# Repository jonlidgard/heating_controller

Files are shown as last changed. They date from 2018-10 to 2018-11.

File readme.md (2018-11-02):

# Raspberry Pi Based Heating Controller

The circuit for this is stored under the kicad directory

# Adafruit Python MCP3008

Python code to use the MCP3008 analog to digital converter with a Raspberry Pi or BeagleBone black.

## Installation

To install the library from source (recommended) run the following commands on a Raspberry Pi or other Debian-based OS system:

    sudo apt-get install git build-essential python-dev
    cd ~
    git clone https://github.com/adafruit/Adafruit_Python_MCP3008.git
    cd Adafruit_Python_MCP3008
    sudo python setup.py install

Alternatively you can install from pip with:

    sudo pip install adafruit-mcp3008

Note that the pip install method **won't** install the example code.

#WiringPi

See jonsblog.lidgard.uk/cross-compile
and info held in cpp/build-libDigiPot

# Heating Controller Code

## This code should be run as a daemon

The heating controller connects to a worcester-bosch combi boiler via the TR2 interface (3 4 F) & acts to control demand for heating.
It has it's own TR2 interface for connecting to the existing thermostat but also has 3 'Call For Heat' connections to allow Nest & other devices to control the boiler in a zoned setup.

Control Flow:
* Set the Boiler output to be off using the X9C digital programmable pots.
* Read the TR2 resistances between 3&4 & F&4 to get thermostat mode and sensed temperature.
* Drive the zone valve & when the zone valve is open:
* Set the Boiler output to mimic those resistances using the X9C digital programmable pots.
* If any CFH contacts made, 

Set the X9C to

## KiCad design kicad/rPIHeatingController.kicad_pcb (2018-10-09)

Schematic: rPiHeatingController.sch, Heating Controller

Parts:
C1, C2, C3, C4, C5, C6, C7, C8, C9, C10, C11, C12, C13, C14: 100n; C_Rect_L4.0mm_W2.5mm_P2.50mm
J1, J2, J15: Screw_Terminal_01x03; TerminalBlock_Altech_AK300-3_P5.00mm
J3, J4, J5, J11, J12, J13, J17, J19: Screw_Terminal_01x02; TerminalBlock_Altech_AK300-2_P5.00mm
J6, J7, J8, J9, J14, J16, J18: Conn_01x06; Pin_Header_Straight_1x06_Pitch2.54mm
J10: Raspberry_Pi_2_3; Socket_Strip_Angled_2x20_Pitch2.54mm
J20: Conn_01x10; Socket_Strip_Straight_1x10_Pitch2.54mm
J21: Conn_01x04_Female; Socket_Strip_Straight_1x04_Pitch2.54mm
J22: Conn_01x03_Female; Socket_Strip_Straight_1x03_Pitch2.54mm
R1, R2, R3, R4, R5, R6: 330R; R_Axial_DIN0207_L6.3mm_D2.5mm_P7.62mm_Horizontal
R7: 4k7; R_Axial_DIN0207_L6.3mm_D2.5mm_P7.62mm_Horizontal
R8: 1k; R_Axial_DIN0207_L6.3mm_D2.5mm_P7.62mm_Horizontal
R9, R11: 3k3; R_Axial_DIN0207_L6.3mm_D2.5mm_P7.62mm_Horizontal
R10: 5k6; R_Axial_DIN0207_L6.3mm_D2.5mm_P7.62mm_Horizontal
R12: 15k; R_Axial_DIN0207_L6.3mm_D2.5mm_P7.62mm_Horizontal
TP1, TP2, TP3: TestPoint; Pin_Header_Angled_1x01_Pitch2.54mm
U1, U2: X9C103P; DIP254P762X533-8
U3: MCP3008; DIP-16_W7.62mm

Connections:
+3V3: J8.3, J9.5, J15.1, J16.5, J20.2, J22.2, R7.1, R8.1, R11.1, R12.1, TP1.1, U3.15 (Vref), U3.16 (Vdd)
+5V: C9.1, C10.1, C11.1, C12.1, C13.1, C14.1, J6.3, J10.2, J10.4, J17.1, J18.1, J20.1, J21.4, J22.1, R1.1, R2.1, R3.1, R4.1, R5.1, R6.1, TP3.1, U1.8, U2.8
ADC1: C1.1, J1.1, R11.2, U3.1 (CH0)
ADC2: C2.1, J1.2, R12.2, U3.2 (CH1)
ADC3: J19.2, R8.2, U3.3 (CH2)
ADC_CLK: J10.12, U3.13 (CLK)
ADC_CS: J10.13, U3.10 (~CS~/SHDN)
ADC_DIN: J10.37, U3.11 (Din)
ADC_DOUT: J10.22, U3.12 (Dout)
CFH1: J9.1, J10.7
CFH2: J9.2, J10.29
CFH3: J9.3, J10.31
CS1_3V: J8.1, J10.35
CS1_5V: J6.1, U1.7
CS2_3V: J8.2, J10.38
CS2_5V: J6.2, U2.7
DS18B20: J10.26, J15.2, R7.2
GND: C1.2, C2.2, C3.2, C4.2, C5.2, C6.2, C7.2, C8.2, C9.2, C10.2, C11.2, C12.2, C13.2, C14.2, J1.3, J3.1, J4.1, J5.1, J6.4, J7.6, J8.4, J9.6, J10.6, J10.9, J10.14, J10.20, J10.25, J10.30, J10.34, J10.39, J11.1, J12.1, J13.1, J14.6, J15.3, J16.6, J17.2, J18.6, J19.1, J20.10, J21.1, J22.3, TP2.1, U1.4, U2.4, U3.9 (DGND), U3.14 (AGND)
INC_3V: J8.5, J10.36
INC_5V: J6.5, U1.1, U2.1
unnamed: C3.1, J3.2, J7.2, R1.2
unnamed: C4.1, J4.2, J7.3, R2.2
unnamed: C5.1, J5.2, J7.4, R3.2
unnamed: C6.1, J11.2, J14.2, R4.2
unnamed: C7.1, J12.2, J14.3, R5.2
unnamed: C8.1, J13.2, J14.4, R6.2
unnamed: J2.1, R9.2, U1.5
unnamed: J2.2, R10.1
unnamed: J2.3, R9.1, U1.6, U2.6
unnamed: J10.8, J21.3
unnamed: J10.10, J21.2
unnamed: J10.19, J20.5
unnamed: J10.21, J20.4
unnamed: J10.23, J20.6
unnamed: J10.24, J20.3
unnamed: J10.27, J20.7
unnamed: J10.28, J20.8
unnamed: J10.40, J20.9
unnamed: R10.2, U2.5
RL1: J10.3, J18.2
RL2: J10.5, J18.3
RL3: J10.32, J18.4
RL4: J10.33, J18.5
UD_3V: J8.6, J10.11
UD_5V: J6.6, U1.2, U2.2
ZV1: J10.15, J16.1
ZV2: J10.16, J16.2
ZV3: J10.18, J16.3

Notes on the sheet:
CFH1
CFH2
CFH3
ZV1
ZV2
ZV3
PWR
RELAYS
TEMP SENSORS
TR2
BOILER
OPTO BOARD
LEVEL SHIFTER
UFH Sensor

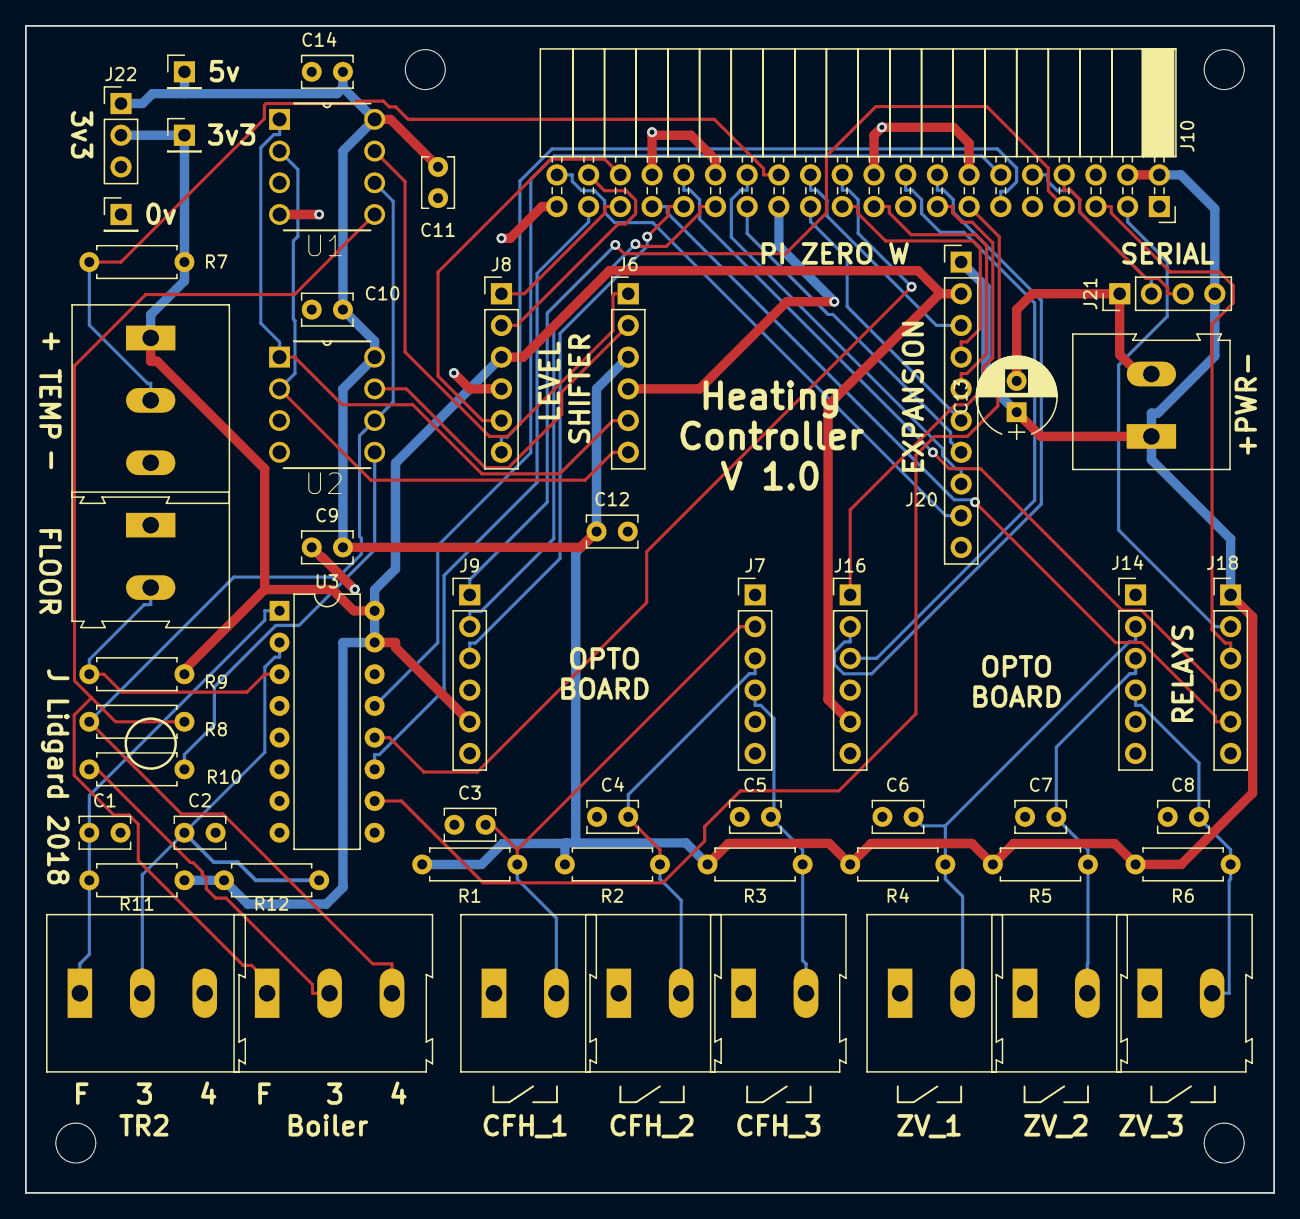
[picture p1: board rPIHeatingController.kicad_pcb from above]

Board: 2 copper layers, 100.0 x 93.5 mm, 54 parts (0 on the bottom side), 48 nets.

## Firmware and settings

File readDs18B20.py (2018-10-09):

# --------------------------------------------------------
# PURPOSE: - To monitor temperatures within a backup server's 
#            case and within the garden shed it is running in
#          - To turn on heating or cooling if temperature within
#            server case gets out of a predetermined range    
#          - To log temperatures/times in a tab-delimited file
#            on a NAS box. 

import os
import glob
import time
import datetime
import RPi.GPIO as iO
import os,subprocess
from subprocess import call
from w1thermsensor import W1ThermSensor

os.system('modprobe w1-gpio')
os.system('modprobe w1-therm')

# ======================================================================
# Define our subroutines:
# --------------------------------------------------
# Define a function to convert Celsius to Fahrenheit 

def celsiusToFahrenheit(theTempCelsius):
 myTempFarenheit = ((theTempCelsius*9)/5) + 32
 return myTempFarenheit
 
# --------------------------------------------------
# Define a function to get current temperature of the
# Raspberry Pi's CPU  (which, just for grins, we also
# want to monitor)

def getPiCPUtemperature():  
 res = os.popen('vcgencmd measure_temp').readline()  
 return(res.replace("temp=","").replace("'C\n",""))  
 
# --------------------------------------------------
# Define a function fo mount the NAS directory as 
# part of the Pi's file system

# NB: For reasons not yet discovered, using the NAS
#     box's name is not working, so we revert to 
#     it's numeric IP address.
#
#     //Giga2/D  works, no problem, but
#     //NAS/A    fails..... go figure....

def mountNasDirectory():
 myUNC="//10.0.0.8/A"
	
 myCmd = "sudo umount " + myLocalMountDir
 subprocess.Popen(myCmd, shell=True)
 
 myCmd = "sudo mount -t cifs " + myUNC + " " +  myLocalMountDir + " -o  uid=pi,gid=pi,user=admin,pass=xxx"
 subprocess.Popen(myCmd, shell=True)


# ======================================================================
# Perform startup processing: 

# -------------------------------------
# Specify the desired temprature range 
# and time between readings

caseTempDesiredC = int(25)
maxDeviation_BeforeCool = 1.5 
maxDeviation_BeforeHeat = 1.5 
secondsBetweenReadings = 60

# -------------------------------------
# Capture the date we started this script

myDateStamp_Startup =datetime.datetime.now().strftime("%Y-%m-%d")
myDateStamp_Today = myDateStamp_Startup

# -------------------------------------
# Specify NAS box directory in the Pi's
# file system's scheme of things
#
# NB: You might have to read up on this: somehow
#     this directory contains some sort of secret
#     sauce that allows the Pi's OS to populate it
#     with shortcuts to the actual NAS box's 
#     folders... possibly specified in the Samba
#     setup files.

myLocalMountDir="/mnt/NAS_A"
 
# -------------------------------------
# Refer to pins by Broadcom SOC channel
# instead of physical pin#

iO.setmode(iO.BCM)

# -------------------------------------
# Specify which pins are used to flip
# which relay switch on/off and then
# define them as "Output"

relayCool = 10
relayHeat = 11
iO.setwarnings(False)
iO.setup(relayCool, iO.OUT)
iO.setup(relayHeat, iO.OUT)

# -------------------------------------
# Turn off both relay switches - for 
# convenience in testing

iO.output(relayHeat, False)
iO.output(relayCool, False)

# -------------------------------------
# Specify the 3 possible heating/cooling states

tempStateNone = 0
tempStateCool = 1
tempStateHeat = 2 

# -------------------------------------
# Set a pointer to our W1Thermsensor object,
# which will give us easy access to the sensors

mySensor = W1ThermSensor()

# -------------------------------------
# Define sensors by ID (we had to experimentally
# discover these by writing a little script that
# opened the W1ThermSensor class, looped through
# the sensors it knew about and displayed "sensorID"
# for each sensor

sensorID_Case = "0000080222f8"
sensorID_Shed = "04165661cdff"

# -------------------------------------
# Mount the share on the NAS box that we
# will be writing the 2 logs to

mountNasDirectory()

# -------------------------------------
# Open the two tab-delimited log files on the
# NAS box: one for each 24-hour period the
# other cumulative since the last startup.
#
# NB: If either file already exists, we want to
#     open it for Append instead of new albeit 
#     with a blank line to call attention to the
#     fact that log entries were interrupted.
#
# NB: We have sometimes been having trouble with 
#     opening a new file failing w/ErrorCode=2 
#     even so the path is good - only to have
#     it work upon re-starting the script.  This
#     happens if/when somebody on another PC deleted
#     one or both log files while the script is running.

myLogFileDelim = "\t"

myFileHeader1 = myLogFileDelim.join(["\n" + "Temp Desired=" + str(caseTempDesiredC), "maxDeviation Before Cool=" + str(maxDeviation_BeforeCool), "maxDeviation Before Heat=" + str(maxDeviation_BeforeHeat)])
myFileHeader2 = myLogFileDelim.join(["\n" + "TimeStamp", "Case TempC ", "Heat/Cool State", "Shed TempC", "Shed TempF", "Pi CPU TempC"])
#myFileHeader2 = myLogFileDelim.join(["\n" + "TimeStamp", "Case TempC ", "Shed TempC", "Shed TempF", "Pi CPU TempC", "Heat/Cool State  (" + str(tempStateNone) +"=Nothing, " + str(tempStateCool) + "=Cool, " + str(tempStateHeat) + "=Heat)"])

myInterruptIndicator = myLogFileDelim.join(["\n" + "-"*45, "-"*45, "-"*45, "-"*45, "-"*45, "-"*45, "-"*45])

myLogFileSingleDay_Path = myLocalMountDir + "/Mongo_TemperatureLogs/MongoTempLog_SingleDay." + myDateStamp_Today + ".csv"
if os.path.exists(myLogFileSingleDay_Path):
	print("SingleDay: Append to Existing")
	logFileSingleDay = open(myLogFileSingleDay_Path, "a")
	logFileSingleDay.write(myInterruptIndicator)
	logFileSingleDay.write(myFileHeader1)
	logFileSingleDay.write(myFileHeader2)
		
else:	
	print("SingleDay: Create New")
	logFileSingleDay = open(myLogFileSingleDay_Path, "a")
	logFileSingleDay.write(myFileHeader1)
	logFileSingleDay.write(myFileHeader2)


myLogFileCumulative_Path = myLocalMountDir + "/Mongo_TemperatureLogs/MongoTempLog_Cumulative.csv"	
if os.path.exists(myLogFileCumulative_Path):
	print("Cumulative: Append to Existing")
	logFileCumulative = open(myLogFileCumulative_Path, "a")
	logFileCumulative.write(myInterruptIndicator)
	logFileCumulative.write(myFileHeader1)
	logFileCumulative.write(myFileHeader2)
else:	
	print("Cumulative: Create New")
	logFileCumulative = open(myLogFileCumulative_Path, "a")
	logFileCumulative.write(myFileHeader1)
	logFileCumulative.write(myFileHeader2)	
	
# ======================================================================
# Drop into the script's main loop, which keeps on executing until the
# script abends or is cancelled:
#
#    - Reading temp, 
#    - Checking to see if we need heating or cooling, and
#    - Writing temps to the log file

while True:
#   --------------------------------------------
#   See if we need to start a new 24-hour log
#
#   NB: re/"a" vs "w".... Greater Minds have decreed
#       there is no sense in using "w"... because
#       with "a" if the file does not exist, it 
#       gets created same as if we used "w".

	myDateStamp_Current  = datetime.datetime.now().strftime("%Y-%m-%d")
	
	if (myDateStamp_Current != myDateStamp_Today):
		myDateStamp_Today = myDateStamp_Current
		myLogFileSingleDay_Path = myLocalMountDir + "/Mongo_TemperatureLogs/MongoTempLog_SingleDay." + myDateStamp_Today + ".csv"
		logFileSingleDay = open(myLogFileSingleDay_Path, "a")
		logFileSingleDay.write(myFileHeader1)
		logFileSingleDay.write(myFileHeader2)	
		
#	--------------------------------------------
#   Loop through the available sensors (only 2 assumed,
#   for which we experimentally determined their IDs 
#   and hard-coded them into this script)
        
	for mySensor in W1ThermSensor.get_available_sensors():
		curSensorID = mySensor.id
		curTempC = round(float(mySensor.get_temperature()),1)
		myTimeStamp = datetime.datetime.now().strftime("%Y-%m-%d@%H:%M:%S")		

#       ---------------------------------------
#       Identify/assign temp as Case or Shed

		if curSensorID == sensorID_Case:
			myTempCaseC = curTempC
		elif curSensorID == sensorID_Shed:
			myTempShedC = curTempC
		else:
			print("Unexpected SensorID=" + curSensorID)
			
#       ---------------------------------------
#       When we have temps for both inside computer 
#       case and shed, turn heating/cooling on/off
#       accordingly and then write to the 2 logs
#
#       Yes, this will break if/when we do not have
#       both sensors present....

        if curSensorID == sensorID_Shed:
#    	    ---------------------------------------
#           Turn heating/cooling on/of as needed
          
			if myTempCaseC> (caseTempDesiredC + maxDeviation_BeforeCool):
				iO.output(relayHeat, False)
				iO.output(relayCool, True)
				curTempState = tempStateCool
			elif myTempCaseC < (caseTempDesiredC - maxDeviation_BeforeHeat):
				iO.output(relayCool, False)
				iO.output(relayHeat, True)
				curTempState = tempStateHeat
			else:
				iO.output(relayCool, False)
				iO.output(relayHeat, False)
				curTempState = tempStateNone
				
#    	    ---------------------------------------
#     	    Write to the logs, flushing the buffers 
#           of each so we can take a look at the files
#           from another PC even while this script is running
#
#           Why are we getting/logging the Pi's CPU temp?
#           In the immortal words of Alfred E. Neuman "Whyyyyyy not?"
#
#           NB that we check to see if each file is still there
#              and re-create as needed just in case somebody somewhere
#              managed to delete one or both log files at the "right"
#              moment
#
#           NB: The "mountNasDirectiory()" thing is an (unsucessful
#               for now...) attempt to get around mysterious "File 
#               Not Found" errors (Error 02)" if/when somebody on another
#               PC deletes one or both log files while the script is running

			myTempPiC = round(float(getPiCPUtemperature()),1)
			myTempCaseF = round(float(celsiusToFahrenheit(myTempCaseC)))
			myTempShedF = round(float(celsiusToFahrenheit(myTempShedC)))
			myLogFileLine = myLogFileDelim.join(["\n" + myTimeStamp, str(myTempCaseC), str(curTempState), str(myTempShedC), str(myTempShedF), str(myTempPiC)])
						
			if os.path.exists(myLogFileSingleDay_Path):
				logFileSingleDay = open(myLogFileSingleDay_Path, "a")
				logFileSingleDay.write(myLogFileLine)
				logFileSingleDay.close
			else:	
				myLogFileSingleDay_Path = myLocalMountDir + "/Mongo_TemperatureLogs/MongoTempLog_SingleDay." + myDateStamp_Startup + ".csv"				
				mountNasDirectory()
				logFileSingleDay = open(myLogFileSingleDay_Path, "a")					
				logFileSingleDay.write(myFileHeader1)
				logFileSingleDay.write(myFileHeader2)	
				logFileSingleDay.write(myLogFileLine)
				logFileSingleDay.close		
												
			if os.path.exists(myLogFileCumulative_Path):
				logFileCumulative = open(myLogFileCumulative_Path, "a")				
				logFileCumulative.write(myLogFileLine)
				logFileCumulative.close
			else:
				mountNasDirectory()	
				logFileCumulative = open(myLogFileCumulative_Path, "a")					
				logFileCumulative.write(myFileHeader1)
				logFileCumulative.write(myFileHeader2)			
				logFileCumulative.write(myLogFileLine)
				logFileCumulative.close

#     	  	-------------------------------------
#    	  	Just for testing/debugging, print some
#     	  	info on the console

			print("ServerCase=" + str(myTempCaseC) + "C / " + str(myTempCaseF) + "F  Shed=" + str(myTempShedC) + "C / " + str(myTempShedF) + "F   TempState=" + str(curTempState) + "   PiCPU=" + str(myTempPiC) + " at " + datetime.datetime.now().strftime("%Y-%m-%d %H:%M:%S")) 
   
	time.sleep(secondsBetweenReadings)
#	sys.exit

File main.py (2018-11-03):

import time, TR2, Boiler, zonevalve, cfh, wiringpi

def setup():
    wiringpi.wiringPiSetup()

    global boiler
    global tr2 
    global valves
    global call_for_heats
 
    boiler = Boiler.Boiler()
    tr2 = TR2.TR2()
    zv1 = zonevalve.ZoneValve(1, zone_valve_state_changed)
    zv2 = zonevalve.ZoneValve(2, zone_valve_state_changed)
    zv3 = zonevalve.ZoneValve(3, zone_valve_state_changed)
    valves = [zv1,zv2,zv3]

    cfh1 = cfh.CFH(1,cfh_state_changed)
    cfh2 = cfh.CFH(2,cfh_state_changed)
    cfh3 = cfh.CFH(3,cfh_state_changed)
    call_for_heats = [cfh1,cfh2,cfh3]
 
    # boiler.set_temp(2000) 
    boiler.off()
   
    for v in valves:
        v.close()


def cfh_state_changed(cfh):
    ch = cfh.get_channel()
    zv = valves[ch]
    if cfh.get_state() == True:
        zv.open()
    else:
        zv.close()


def zone_valve_state_changed(zv):
    any_valve_open = False
    for ch in range( len(valves) ):
        cfh = call_for_heats[ch]
        zv = valves[ch]
        # Only want boiler on if valve is open & a valid call for heat on that channel
        print ('Valve',ch,zv.get_state(),'CFH',cfh.get_state())
        if zv.get_state() == "open" and cfh.get_state() == True:
            any_valve_open = True
            break

    if any_valve_open:
       print ('Boiler:ON')
       # boiler.on()
        
    else:
       print ('Boiler:OFF')
       # boiler.off()


def loop():
    for v in valves:
        v.poll()
    
    for cfh in call_for_heats:
        cfh.poll()



if __name__ == "__main__":
    setup()

    while True:
        loop()
        time.sleep(.5)

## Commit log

2018-10-09 Early commit
    [rPIHeatingController-B.Cu.gbr, rPIHeatingController-B.Mask.gbr, rPIHeatingController-B.SilkS.gbr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]
2018-10-09 Fixed a few error but still not working
    [adc.py, cfh.py, common.py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]
2019-11-02 Fixed missing Boiler widget
    [heating.py]
2019-11-02 Added filesystem status file - heatingStatus
